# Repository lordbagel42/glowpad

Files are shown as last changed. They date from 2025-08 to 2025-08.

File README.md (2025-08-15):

# GLOWPAD

The glowiest macropad

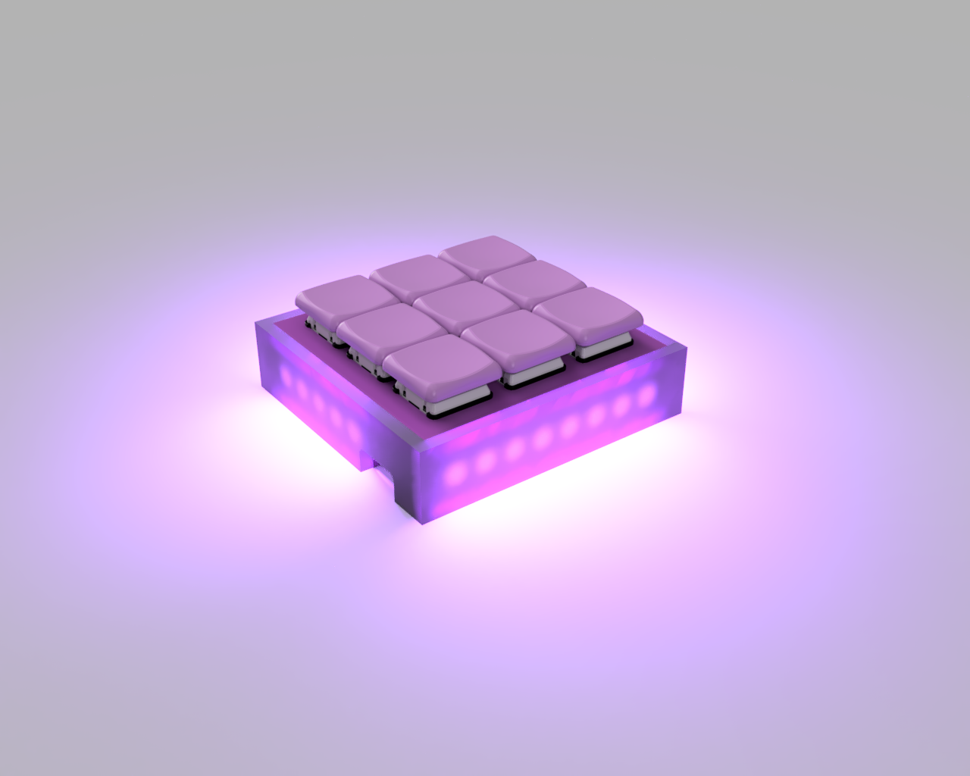
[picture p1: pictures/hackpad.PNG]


This macropad was designed as a sort of sidestep from a Hackpad. I didn't want to make another PCB as I just don't want to deal with the lead time, plus I think hand-wiring a keyboard would be fun, and a macropad is really just a small keyboard.

This will also act as a dongle for my split keyboard, which should increase the battery life of the left half almost 3 months. This is why it uses a nrf52840 based chip rather than the xiao rp2040, it needs the wireless features.

I don't know if I can actually call this a hackpad because its using acrylic side panels and handwire, but it pretty much is a hackpad.

# BOM

| PART | UNIT COST | QUANTITY | ROW COST | NEED BOUGHT | SUPPLIER |
| --- | --- | --- | --- | --- | --- |
| Choc Keyswitch | $5.50 | 1 | $5.50 | TRUE | [typeractive.xyz](https://typeractive.xyz/) |
| MBK Choc Keycap | $3.50 | 1 | $3.50 | FALSE | [typeractive.xyz](https://typeractive.xyz/) |
| THT Diodes | $0.98 | 10 | $9.80 | FALSE | aliexpress |
| Acrylic, 75mmx70mm | $0.00 | 1 | $0.00 | FALSE | [typeractive.xyz](https://typeractive.xyz/) |
| 1m 144led/m WS2812B LED Strip | $13.63 | 1 | $13.63 | TRUE | [typeractive.xyz](https://typeractive.xyz/) |
| Promicro nrf52840 | $3.00 | 1 | $3.00 | TRUE | aliexpress |

total needed: $35.43

# wiring



The wiring is just a standard matrix, it'll end up looking something like this.

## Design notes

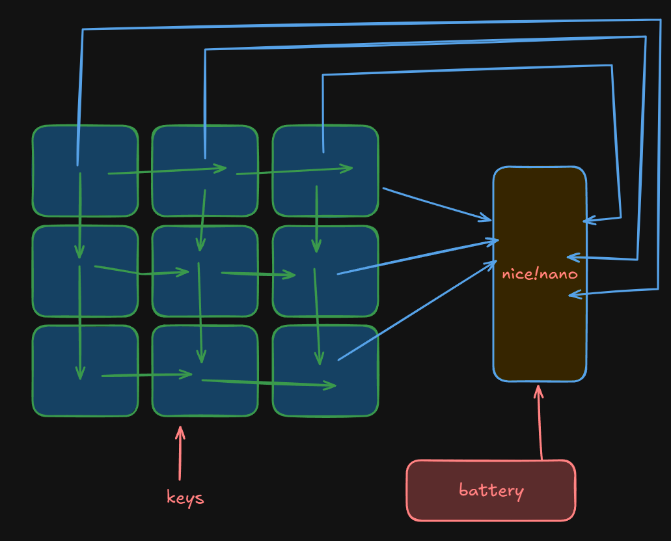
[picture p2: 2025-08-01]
chrome_AgvCGvt9Wk.png

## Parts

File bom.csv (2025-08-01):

PART | UNIT COST | QUANTITY | ROW COST | NEED BOUGHT | SUPPLIER
Choc Keyswitch | $5.50 | 1 | $5.50 | FALSE | https://typeractive.xyz/
MBK Choc Keycap | $3.50 | 1 | $3.50 | FALSE | https://typeractive.xyz/
THT Diodes | $0.98 | 10 | $9.80 | FALSE | aliexpress
Acrylic, 75mmx70mm | $0.00 | 1 | $0.00 | FALSE | https://typeractive.xyz/
1m 144led/m WS2812B LED Strip | $13.63 | 1 | $13.63 | TRUE | https://typeractive.xyz/
Promicro nrf52840 | $3.00 | 1 | $3.00 | FALSE | aliexpress

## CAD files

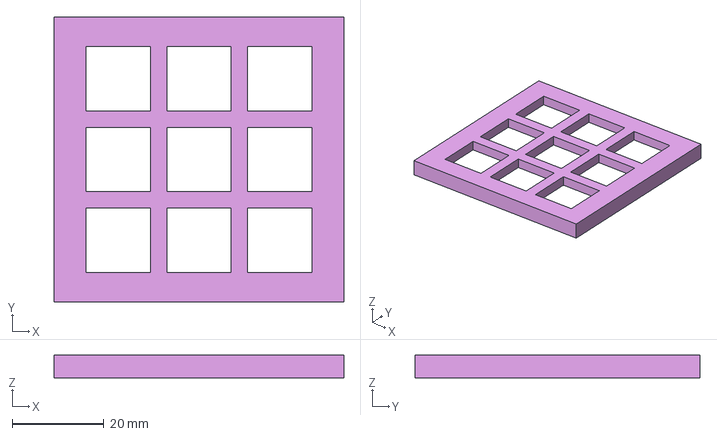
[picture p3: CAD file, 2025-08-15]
plate.step
63.2 x 62.2 x 5.00 mm

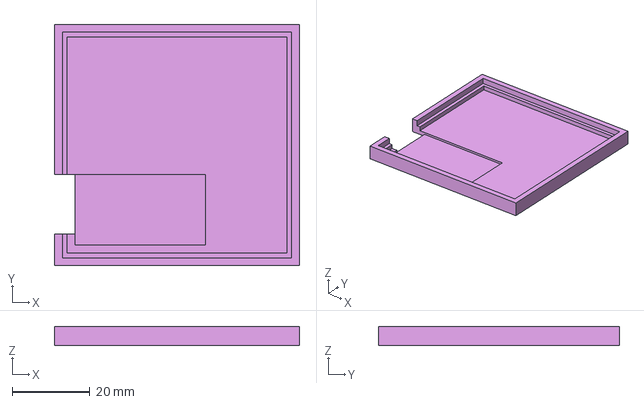
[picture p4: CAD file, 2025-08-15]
base.step
63.2 x 62.2 x 5.00 mm

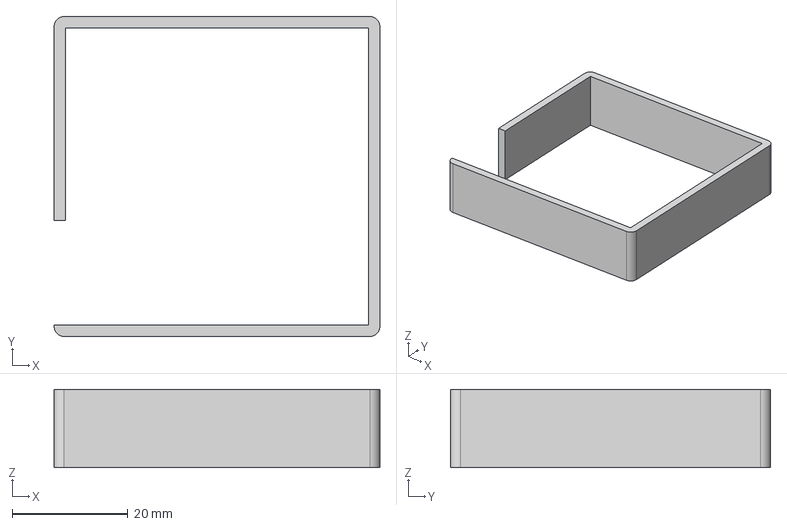
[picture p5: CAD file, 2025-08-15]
walls.step
56.2 x 55.2 x 13.5 mm

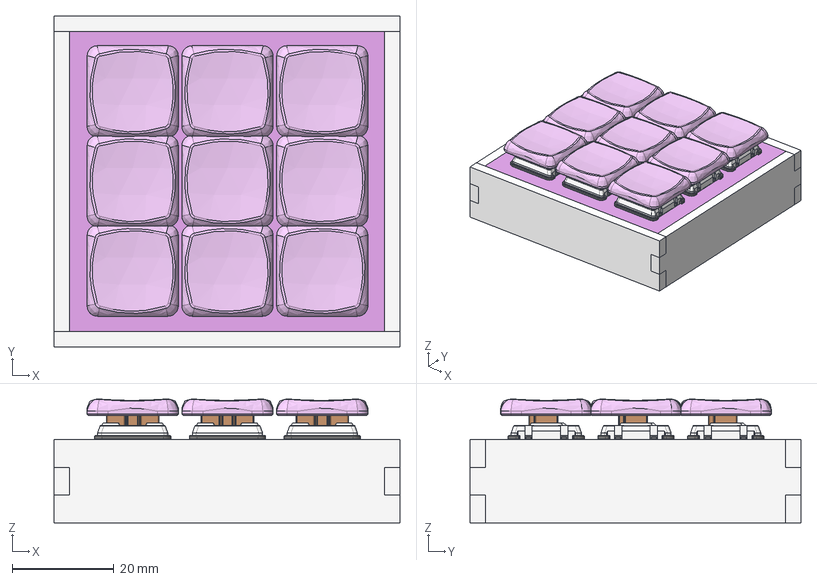
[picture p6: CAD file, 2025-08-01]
Glowpad.step
67.9 x 64.9 x 24.3 mm
Pads x 168
WS2812 LED Chip x 168
PCB Strip x 28
SMD x 84
Base
LED_0603_1608Metric_ON v1
nice!nano v1.0 x 65
USB_C_Receptacle_16P_TopMnt_Horizontal_GCT_USB4105-xx-A
USB_C_Receptacle_16P_TopMnt_Horizontal_GCT_USB4105-xx-A024
Pin4
USB_C_Receptacle_16P_TopMnt_Horizontal_GCT_USB4105-xx-A002
USB_C_Receptacle_16P_TopMnt_Horizontal_GCT_USB4105-xx-A026
USB_C_Receptacle_16P_TopMnt_Horizontal_GCT_USB4105-xx-A022
Pin2
Pin6
Resistor_0603_1608Metric v1_3
USB_C_Receptacle_16P_TopMnt_Horizontal_GCT_USB4105-xx-A004
Pin9
USB_C_Receptacle_16P_TopMnt_Horizontal_GCT_USB4105-xx-A021
Pin7
Resistor_0603_1608Metric v1_2
USB_C_Receptacle_16P_TopMnt_Horizontal_GCT_USB4105-xx-A005
Pin10
LED_0603_1608Metric_ON v1(Mirror)
USB_C_Receptacle_16P_TopMnt_Horizontal_GCT_USB4105-xx-A007
Pin11
Crystal Oscillator v3
USB_C_Receptacle_16P_TopMnt_Horizontal_GCT_USB4105-xx-A017
Pin14
Resistor_0603_1608Metric v1
USB_C_Receptacle_16P_TopMnt_Horizontal_GCT_USB4105-xx-A019
Pin16
USB_C_Receptacle_16P_TopMnt_Horizontal_GCT_USB4105-xx-A023
Pin5
USB_C_Receptacle_16P_TopMnt_Horizontal_GCT_USB4105-xx-A001
USB_C_Receptacle_16P_TopMnt_Horizontal_GCT_USB4105-xx-A025
Pin3
USB_C_Receptacle_16P_TopMnt_Horizontal_GCT_USB4105-xx-A003
USB_C_Receptacle_16P_TopMnt_Horizontal_GCT_USB4105-xx-A035
USB_C_Receptacle_16P_TopMnt_Horizontal_GCT_USB4105-xx-A020
Pin1
Pin8
Resistor_0603_1608Metric v1_1
Capacitor v1
USB_C_Receptacle_16P_TopMnt_Horizontal_GCT_USB4105-xx-A006
Pin12
Capacitor v1_1
USB_C_Receptacle_16P_TopMnt_Horizontal_GCT_USB4105-xx-A008
Pin13
Crystal Oscillator v3_1
USB_C_Receptacle_16P_TopMnt_Horizontal_GCT_USB4105-xx-A018
Pin15
Acrylic Left
Acrylic Right
Acrylic Back
Acrylic Front
Walls
Plate
Document x 63
keycap v14 x 9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

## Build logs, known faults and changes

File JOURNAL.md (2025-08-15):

---
title: "Glowpad"
author: "Raygen Rupe"
description: "Its a macropad there isn't much to it. Except it does glow which is cool"
created_at: "2025-07-31"
---

## total time spent: like 12 hours this thing was horrible to make.

# the glowie thing

### date: june 26

I made this thing a while ago and I don't remember most of it, nor do I have photos of any of it anymore to be honest.

This macropad is meant to just be simple and fun to put together, its part of why I've set it up to be handwired. I also wanted it to be really, really small. Since I'm using a nice!nano clone I can't really use a PCB and make it this size, there isn't anywhere to put it. This is my best attempt of finding a location and even this just a little bit too sketchy for me to try.

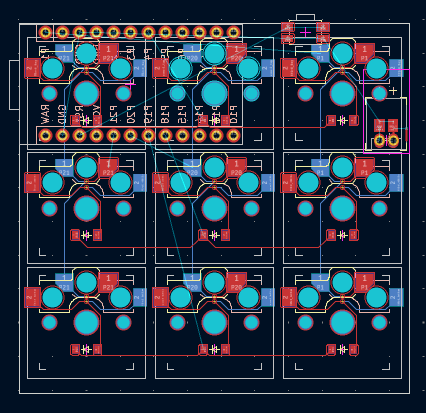
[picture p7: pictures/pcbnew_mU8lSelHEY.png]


This is pretty as small as is possible for a 3x3 choc macropad and I wanted to keep it that way. Unfortunately not using a PCB means that this journal has to exist because it technically isn't a hackpad anymore, so.... that's fun.

# i'm writing this journal 20 minutes before the deadline help me

I started out this macropad with one master sketch. Most of these numbers are just to define Choc and MBK spacing but that little 1.1 gap was kinda unique, I had to use my printers scanner to scan a Choc with an MBK keycap on it to find that was the correct offset.

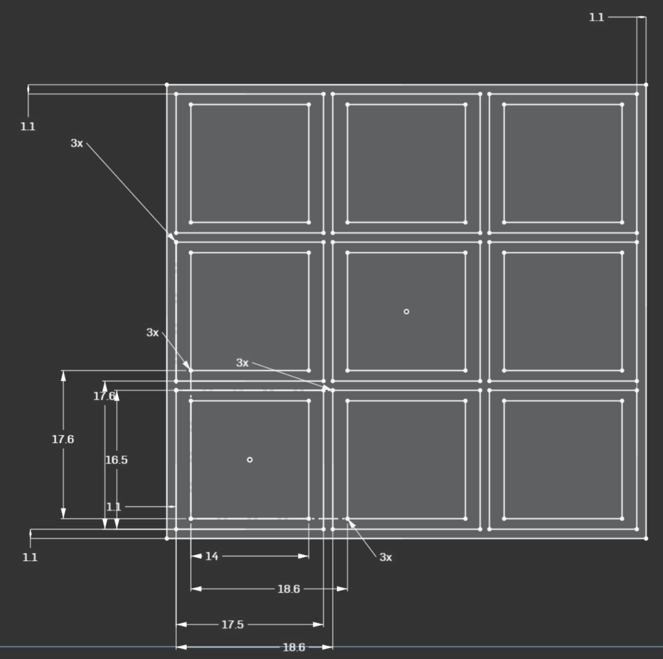
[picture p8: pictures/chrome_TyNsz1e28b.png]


This is when things got weird. I then made a sketch on top of this one to define the acrylic area and the space for the LED's to go.

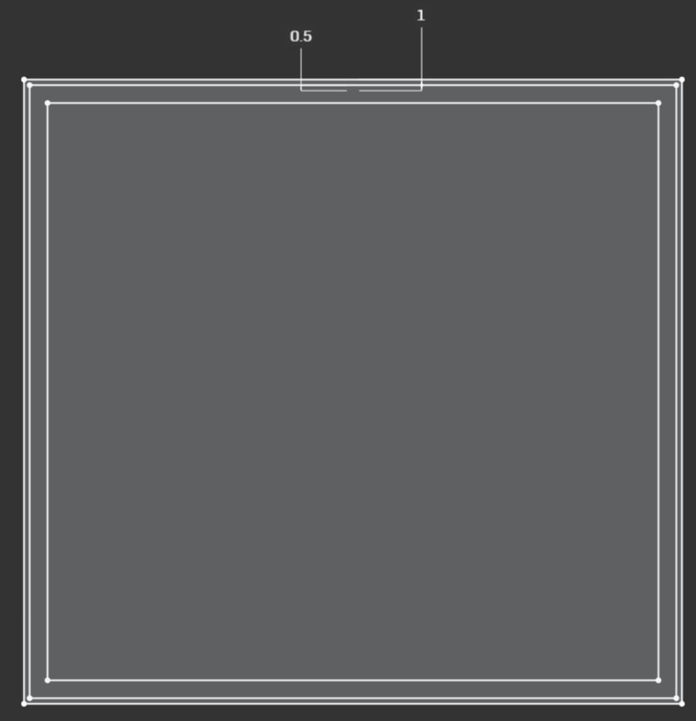
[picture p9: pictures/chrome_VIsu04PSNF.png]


This was a bad idea. I should've done it all in one sketch, this came to bite me later.

Yadda yadda yadda couple extrudes later and I had this.

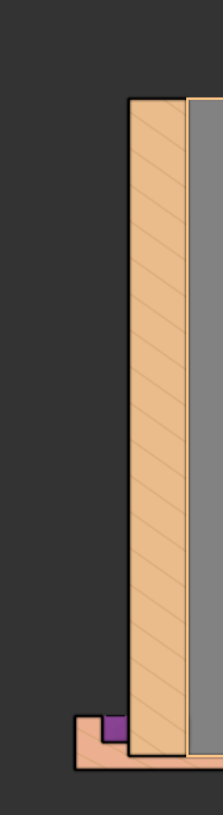
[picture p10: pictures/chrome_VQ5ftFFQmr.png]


A little slot for the LED strip to sit in and hold it in place. Couple more extrudes and I had a full plate.

Voila. An enclosed space for the LED.

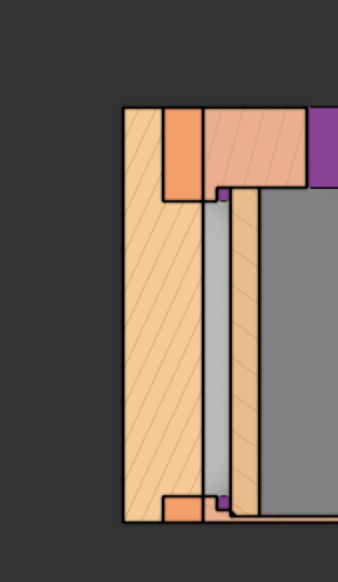
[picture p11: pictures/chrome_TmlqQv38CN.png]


There is one teeny tiny little detail I have to point out though: LED's have a thickness to them. It's actually quite a noticeable one, too. I only realized this after about 6 hours of fighting OnShape and trying to make my assembly work. Thats what the little spot in the middle of this photo is; I came back and fixed things.

I also did a bit of a direct modeling hack. Onshape lets you just delete a part, so I just added on to the sketches in the past and deleted the acrylic that was the wrong sizing. New stuff here we go:

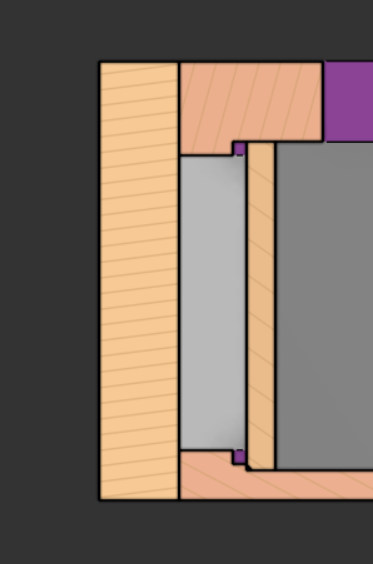
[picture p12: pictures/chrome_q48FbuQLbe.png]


Much better. I can actually fit an LED in here, like this:

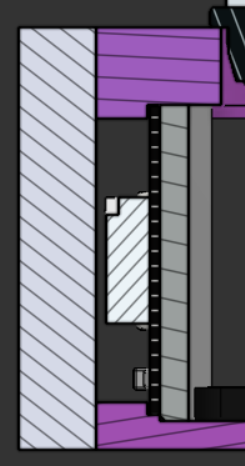
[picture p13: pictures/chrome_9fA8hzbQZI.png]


This leads to the final, lovely finished product after a painstaking and horrible 12 hours trying to make it. When I try and look back to remember what I did, all I remember is being mad at myself for not planning for the LED thickness. Oops.

This was honestly a really informative thing. It's the first time I used Delete Part, something I now make use of often in combination with the derived tool.

# build time!!! :3

Build went honestly pretty good. I had to reprint all the parts 4 times because my printer was dying but I ended up just using my schools printer and it went great. The acrylic pieces were also perfectly cut the first time I tried, totally guessing the settings. I'm very proud of that lmao.

I also printed out some little triangles to lightly glue to the acrylic pieces and make things square and that.... was not a good idea. Some superglue leaked out of one of the places it was supposed to go and mixed with the glue stick I had in and just welded the triangle to one of the acrylic pieces. When I went to remove the triangle it just snapped the acrylic sadly.

Soldering it was a lot of fun. I just kinda sent it and did whatever. I didn't use diodes because I can't find my bag of them and I don't think I need NKRO on a macropad lol.

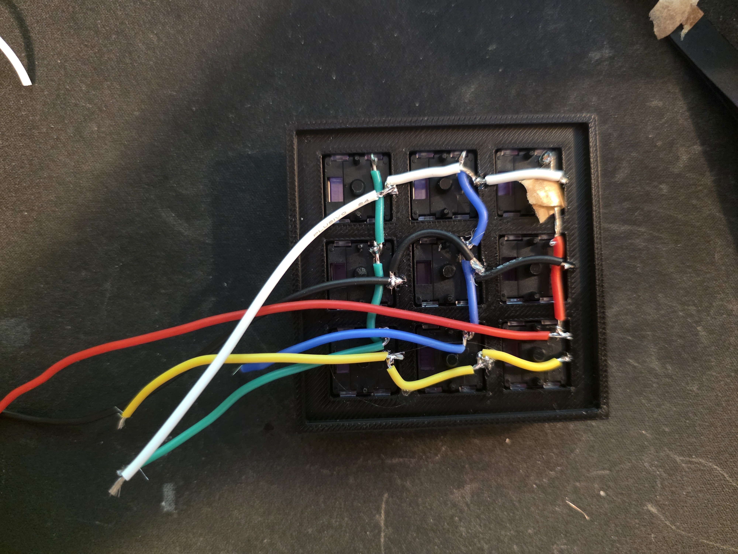
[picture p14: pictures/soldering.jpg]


Is it good soldering? Nope. Does it work? Yup.

It only took about an hour to put this together. The ZMK config is nothing special, the example snippets are mostly for a 3x3 macropad so it made this really easy. I'm going to add a battery to this once I find my bag of little switches and cut a hole for one in.

I'll update this once I have the LED's installed, Amazon sadly delayed it so it arrives past the deadline. I think the acrylic is thin enough but I might have to redo it with clear acrylic, not sure yet.
